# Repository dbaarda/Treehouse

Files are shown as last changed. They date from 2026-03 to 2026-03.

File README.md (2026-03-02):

# Treehouse README

## Introduction

I'm building a treehouse, and it needs to be documented.

## Contents

  Name          Description
  ------------- ------------------------------------------------
  README        This file.
  AUTHORS       The main project authors.
  THANKS        All the project contributors.
  COPYING       Copyright and licencing details.
  INSTALL       Installation instructions.
  USAGE         Usage instructions.
  SUPPORT       Support details and instructions.
  DEVELOPMENT   Development details and instructions.
  DESIGN        Design details and description.
  TODO          List of outstanding tasks and future plans.
  NEWS          Summary of fixes and changes for each release.
  ChangeLog     Detailed development change history.
  doc/          Contains project documentation.
  src/          Contains project source code.
  tests/        Contains project unit and functional tests.

in the distribution for bits and pieces.

## Credits

This should list original authors, significant contributors, and related
contributing projects.

See AUTHORS and THANKS for contributors to this project.

## Conditions

be the copyright and licencing terms and condtions.

See COPYING for the copyright and licencing details.

## Install

See INSTALL for installation instructions.

## Usage

reference to man pages or documentation in doc/, or the following;

See USAGE for usage instructions.

## Support

including mailing lists, discussion forums, online documentation,
trackers, etc. It should also include instructions or pointers to
instructions on procedures and conventions when using them.

### Documentation

documentation, FAQ\'s etc.

<http://www.project.net/>

:   The project homepage.

<http://wiki.project.net/>

:   The project wiki site

### Discussion

forums, giving any necissary subscription information etc.

<http://lists.project.net/project-announce>

:   Low volume project announcements list.

<http://lists.project.net/project-users>

:   User discussion list.

<http:///lists.project.net/project-devel>

:   Developer discussion list.

### Reporting Problems

any useful links.

<http://www.project.net/doc/bug_procedure.html>

:   Online instructions for reporting bugs.

<http://tracker.project.net/>

:   The projects bug tracker.

## Development

See DEVELOPMENT for development instructions.

## Design

See DESIGN for the design details and description.

## Plans

See TODO for future plans.

## History

See NEWS and ChangeLog for past history.

------------------------------------------------------------------------

<http://project/url/README> \$Id: README,v 82b72fe70897 2021/03/12
00:35:22 abo \$

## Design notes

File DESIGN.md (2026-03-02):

# *Project* DESIGN

::: contents
**Contents**
:::

## Introduction

### Identification

This is the \<Software Design Document\> for the \<Project Name\>.
\<Project Name\> is being developed according to \<SDP-DocId\>
\"Software Development Plan for the \<Project Name\>\". The requirements
for \<Project Name\> are identified in the \<SRS-DocId\> \"Software
Requirements Specification for the \<Project Name\>\".

### Document Overview

### System Overview

## Design Details

### Inspirations and Origins

### Design Philosophy

### General Architecture

#### Wall bracing

Diagonal bracing is needed for walls, floor and roof.

Turns out it's pretty much essential for ensuring your walls are true/square.
I used ratchet-straps to bring the walls square before putting on the
gavanized strapping to ensure the strapping was tight enough... there's a
limit to how much the strap tightners can do. Another tip; put the first nail
all the way through a strap-hole, tilt the nail a bit in the direction you
want to tighten it before starting to hammer it in. As it goes in it will pull
the strap tighter.

Need additional 4.5*2 + 1.8*2 = 12.6m

#### Cavity Battens

Using foilboard as the moisture barrier for both walls and roof means I'll
need cavity battens for both.

Cavity battens are to give a cavity gap between the wall
foil/moisture-barrier/sarking and the outer cladding. This gap is so moisture
that gets to, or condenses on, the barrier can drain down and to allow airflow
to help evaporation. The cavity also improves foil insulation performance with
gaps of at least 20mm recommended, but 10mm is sufficient for drainage/ventilation.

The bottom of the cavity is sealed with a perforated cavity closer that allows
drainage/airflow but blocks pests. Sometimes there is also a cavity top-vent
to give even better airflow while preventing easy water ingress.

For vertical corrigated sheet cladding an alternative cavity-closer is
flashing that protrudes past the outer edge of the cladding, leaving a small
gap for ventilation but small enought to prevent pests.

Simple cavity battens are normally rectangular profile strips installed mostly
vertically on top of the barrier and attached to the studs behind them. The
attachments are usually staggered nails, leaving the middle of the batten
clear to put the horizontal cladding attachments through (long nails or
screws), but sometimes glue or tape fixing is sufficient and the cladding
attachments through the batten to the studs becomes the primary attachment.
This vertical batten arrangement gives a clear gap for moisture to drain down.
They can also sometimes be put horizontally on top of noggings, but then there
is a minium 50mm gap on either end to allow vertical drainage/airflow and they
are mounted at a 5deg angle to drain water off them.

For mounting wall cladding vertically instead of horizontally, the attachment
points tend to be horizontally aligned, requiring the cavity battens to be
horizontal. For this castellated cavity battens are normally used. These
include castelated cutout "gaps" on both sides of the batten to allow vertical
flow/drainage past them on both the barrier side, and the cladding side. They
also include a 13|15|18 degree bevelled/sloped top side so that moisture drains
away from the barrier towards the cladding. Sometimes the bottom is also
bevelled to prevent moisture wicking back to the barrier on the bottom of the
batten. In theory a drip-cut could also help, but I've not seen that.
Standards require at least 1000mm^2/m worth of gaps past the batten, but most
castelated battens have at least 2x that much, with 20x5mm castelations
alternating on both sides.

With horizontal battens, there is often not a corresponding horizontal line of
noggings/studs to directly attach the batten to. In this case, structural
battens can be used, which are strong enough to directly attach the cladding
to without a stud directly behind the cladding attachemnt point.

There are also platic battens, that usually have corrigation-like ventilation
through them for mounting horizontally. They are typically not structural.

https://www.ventsystems.com.au/products/vb20-wall-cavity-batten/

For the walls, with vertical polycarbonate cladding we need horizontal cavity
battens. Note that the greca profile is itself already "castelated" with
16mm/2 * 1000mm = 8000mm^2/m of ventilation even if directly attached to the
foilboard. However, foil insulation will do better with an additional gap. We
can get away without castelated battens provided we either have regular 50mm
gaps and mount them on 5deg angles (a pain), or put a bevelled edge on the top
(and probably bottom) to drain towards the cladding to run down the greca
"castelation gaps". Given the castelation gaps, we can probably get away with a
smaller gap of maybe even 5mm?

For the roof, the structural roof battens that the polycabonate roofing is
attached to are run "horizontaly" perpendicular to the roof slope. This means
we cannot just put them on top of the roof foilboard membrane, but need to add
"vertical" cavity battens under them over the rafters. The roof battens add a
35mm gap between the foilboard and roof sheeting which helps insulation, and
the sheet "castelation gaps" allow "vertical" airflow over the roof batten,
but a gap is still needed for drainage flow under them. These are sometimes
called "counter-battens".

The roof cavity battens need to provide a drainage gap of at least 5mm under
the roof battens. They also need to help distribute the load from the roof battens
so that it doesn't just crush into the foilboard. This means we can't just put
square spacers under where the roof-battens attach through the foilboard to
the rafters.

We are going to need 3 walls * 4 strips * 3m + 1 wall * 3 strips * 3m + 8 rafters
* 3.6m ~= 75m of cavity battens.

I originally thought of using [Weathertex 1220 x 45 x 9.5mm Cavity
Batten](https://www.bunnings.com.au/weathertex-1220-x-45-x-9-5mm-cavity-batten_p0240107)
which work out as $2.15/m. 

Then I realized I could cut a 90x35mm MPG10 beam into 8 35x9mm cavity battens.
For a more normal batten size that would distribute the foilboard load a
little better you could cut 6 44x10mm battens, or use 90x45 for 8 45x9mm
battens. For MPG10 H3 90x35mm costing $5.95/m the battens would be ~$0.75/m or
~$1/m, and for MPG10 H3 90x45mm costing $7/m they would be $0.88/m.

Wooden battens must be at least H3 treated to protect them from rot, and cut
H3 timber needs to be re-treated on the cuts with H3 level timber
preservative. Cut into strips like this so much needs re-treating you might as
well use untreated pine (MPG10 untreated 90x35 for $4/m, or $0.50/m battens)
and treat it all afterwards, or even non-structural pine (non-structural 90x45
$3.20/m or $0.40/m).

Bunnings only has sprayon cut sealers, 300g for $19.50. There is also
brushon/soak stuff available at Pestrol Australia at 2L for $49.90. You need
0.25l per m^2, or about 70m of 45x10mm battens per 2L tin, adding $0.71/m to
the cost, bringing even the cheapest non-structural battens to $1.11/m.

* [TWA Woodcare 300g Ecoseal Tanalised Timber Treatment
(H5)](https://www.bunnings.com.au/twa-woodcare-300g-ecoseal-tanalised-timber-treatment_p0960107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)

* [Tanalised 300g Clear Enseal Timber Treatment
(H3)](https://www.bunnings.com.au/tanalised-300g-clear-enseal-timber-treatment_p0960108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)

* [XJ Timber Preservative 2L](https://www.pestrol.com.au/buy-online/xj-timber-preservative/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)

This makes the Weathertex battons look more appealing. Less work and no nasty
treatment costs/process. They will probably still need bevelling for the
horizontal wall battons. Not much info on what they are made of (hardwood?)
but I suspect it's a hardwood composite that will not need treating.

Other options are [permatimber 42 x 18mm DAR]
(https://www.bunnings.com.au/permatimber-42-x-18mm-2-7m-arctic-white-pvc-composite-dar_p0497592)
cut into 2 42x7.8mm battens ($5.44/2 = $2.72/m battens).

[42x11mm 5.4m H3 Treated Pine FJ DAR Primed
LOSP](https://www.bunnings.com.au/42-x-11mm-5-4m-h3-treated-pine-fj-dar-primed-losp_p0020736)
used as-is for 42x11mm battons ($4.11/m), but will also need beveling and cut
treating.

[QuickBoard 300 x 9mm 2.7m Arctic White PVC VJ Wall and Ceiling Lining Board -
2
Pack](https://www.bunnings.com.au/quickboard-300-x-9mm-2-7m-arctic-white-pvc-vj-wall-and-ceiling-lining-board-2-pack_p0497624)
cut into either crosswise 60 45x9x300 bits that can be chained together ($59/2/(2700/45)/0.3 = $1.64/m), or 6
45x9x2.7m strips ($59/2/6/2.7 = $1.82/m). Note these are hollow, hence chained bits would be like a
vented plastic batton.

[QuickBoard 300 x 9mm 2.7m Antique White PVC VJ-Crown
Reversible](https://www.bunnings.com.au/quickboard-300-x-9mm-2-7m-antique-white-pvc-vj-crown-reversible-2-pack_p0497612)
cut into 6 45x9x2.7m strips ($89/2/6/2.7 = $2.74/m).

[Brutus 6 x 38mm x 3m Building Moulding Cover
Trim](https://www.bunnings.com.au/brutus-6-x-38mm-x-3m-building-moulding-cover-trim_p1100628)
$10.92/3=$3.64/m

XPS foam! This is a DIY version of [Ametalin 2750x43x12mm ThermalBreak
strips](https://www.bunnings.com.au/ametalin-2750mm-x-43mm-x-12mm-thermalbreak-strips-r0-25-pack-of-50_p0401288)
which cost $458.07/(50x2.75) = $3.33/m. Compression strength is about 200kPa,
so a 70x50mm patch can take about 71kg or a 50mm strip can take more than 1000Kg/m.  Note foilboard compression
strength is about 70kPa so about 250kg/m on a 35mm wide joist. A 1200x600x50mm
sheet cut into 50 1200x50x9.5mm battens (table saw 2.5mm swarf) or 60
1200x50x10 battens (hotwire) ($29.8/(50x1.2) = $0.50/m).

https://www.bunnings.com.au/bastion-1200-x-600-x-50mm-xps-multi-use-foam-board_p0461084

Fluteboard! It looks very similar to vented cavity battens. Note it can also
be used as a cavity closer! The following cavity battens and all the related
products look like they have been made from laminated fluteboard;

https://www.ventsystems.com.au/products/vb20-wall-cavity-batten/
https://proctorgroup.com.au/construction-membranes/proctorpassive-drainage-batten-db-fr/

It's hard to get data on compression strength, but it looks like it will be
between 140kPa and 1.4MPa(???) Testing a 4x5cm piece of corflute it took about
30Kg before it collapsed. Thats 30*9.81/(0.05*0.04)=147150Pa=147kPa which
matches the 140kPa number above. A 70x50 patch can take only about 50Kg, or
for a 50mm strip about 713Kg/m. As per the cavity battens, it seems 4mm holes
are a sweet spot to prevent capilary action and block pests, so the
1200x900x5mm $14 tunnelcore is the thinest you'd want. There is also
2250x1220x8mm $35, which gives a bigger gap, but the holes a bigger and might
need a mesh. Note metal mesh with <2mm holes is a requirement for fire safety
to protect against embers, so maybe we need a mesh anyway.

You might want to stack 2x5mm for 10mm or 4x5mm for 20mm, if you do you could
"brick" the layers to get wider than 900mm lengths. Unfortunately
polypropyline is a bitch to glue;

https://forgeway.com/learning/blog/bonding-polypropylene-with-glue

There are special polypropyline glues but they are complicated and very
expensive. Corflute suggests hot glue or double sided tape. Other sites
suggest contact-adhesive. I've seen suggestions to use welding with a hot-air
gun, which would work well but might be very hard to do properly without
deforming everything. There is also triple-wall fluteboard available
(2200x1100x10mm $55.30, min purchase 5 for $276.49), but it's harder to find;

https://www.silverback.com.au/FLUTEB/Flute-Board-Gorilla-Sheets/pd.php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

Note that ultimately these will be mechanically fixed together with the
wall/roof mounting screws that go through to the frame/batton, so the strength
of the laminating bond probably doesn't matter much. Perhaps a light
heat-weld, contact adhesive, or double-sided-tape would be enough?

Testing with cheap double-sided tape, expensive double-sided tape, and cheap
contact adhesive, they all worked really well, way better than is required. I
suspect this is because the white tunnelcore is "corona treated" to make the
surface easier to print on.

Cutting a 1200x900x5mm sheet and laminating two layers can give 13 900x45x10mm
battens ($14/13/0.9 = $1.20/m), or can be "bricklayed" into longer battens.

2440x1220x5mm sheets can be bought on ebay, but only in packs of 10 for $340.

Using a single layer 2250x1220x8mm cut into 50 1220x45x8mm battons $35/50/1.22
= $0.57/m

This could also be done using [Sunlite 8 1200x610x8mm Clear Twinwall
Polycarbonate Sheet](https://www.bunnings.com.au/sunlite-8-1-2-x-0-61m-clear-twinwall-polycarbonate-sheet-1200mm_p1010852)
giving 25 0.61mx45x8mm battens ($29.76/25/0.61 = $1.95/m), or [Sunlite 10mm
Twinwall 1000x980x10mm Clear Polycarbonate Roofing $36.80
](https://www.bunnings.com.au/sunlite-10mm-twinwall-x-1-0m-clear-polycarbonate-roofing-1000mm_p1010830)
giving 21 0.91mx45x10mm battens ($36.80/21/0.91 = $1.93/m).

Finally, what about cutting strips of foilboard to use as a cavity batten?
cheap, and dispite the good enough compression strength, too easy to snap to
be worth even trying? The 10mm foilboard is a tiny bit cheaper than 8mm
tunnelcore per m^2.

#### Ventilation and Drainage

The http://ventsystems.com.au/ provides both an awesome set of ventilation
products, and a wealth of information on design and standards. Sadly their
products don't seem easy to get, and are probably really expensive. Their docs
pointed me at the existing standards, which are also freely available and very
good;

https://ncc.abcb.gov.au/editions/ncc-2022/adopted/housing-provisions

Standards say for a <10deg traditional mono-pitched roof requires 25000mm^2/m
at opposing ends of the roof. That's effectively a 25mm ventilation gap on the
entire length of the top and bottom sides of the roof.

For walls, NZ regs require cavity closers to have at least 1000mm^2/m at the
bottom. Top vents appear to be recommended but optional. I cannot find
Australian regs except related to fire protection which required metal mesh
with max 2mm openings to block embers from getting into the cavity. It seems
NZ regs are the leaders on wall cavity best practice.

The wall cavity gaps between foil/sarking is recommended to be 20mm, but with
profiled sheets the crests add their own 16mm cavity (avg 8mm gap). Also, the
20mm gap was largely to avoid "bulging of underlay" closing the gap, which
cannot happen with foilboard, and studies say a 10mm gap is probably
sufficient. Castelated cavity battens have 5mm deep gaps, and So I belive 9~10mm cavity battens would be sufficient for the
walls.

#### Tree holes

Holes for branches through treehouse walls, floors, and roofs need to be
somehow sealed against insects/rain/etc while still allowing the trees to grow
and move in the wind.

Holes at the floor level will have 40mm of clearance around the tree to allow
for alignment errors, tree growth, and movement.

Higher up in the tree branches are thinner and can move more, so we allow 50mm
of clearance.

Sealing the hole needs a flexible but robust seal against the tree to the roof
sheets, wall cladding, or floor. This needs to have a water-tight seal to the
external boards/sheets/cladding that will not interfere with the water flow.
It should also be robust enough to resist critters and have strong UV/weather
resistance.

Also, another layer of sealing should be done for the foilboard moisture
barrier, which should also be watertight. This should be protected by the
outer layers from critters/UV/weather, so it does not need to be as robust. It
needs to have a waterproof attachment to the foilboard.

The attachment to the tree needs to be waterproof without hurting the tree or
restricting growth and movement. This means it needs to have minimal (ideally
zero) holes/screws/etc into the tree, and be loose or stretchy enough to not
hurt tree growth and cause tree girdling injurys.

These suggest a flexible rubber membrane attached to the tree and treehouse
with butyle tape. To go around the tree it needs to be initially wrapped and
then joined to itself with a waterproof seam. Joins and seams can be
reenforced with pop-rivets through punched holes and small washers, and sealed
with butyle tape.

The butyle tape needs to be stretchy, without any fiber/fabric/aluminium
re-enforcement that limits the stretch. double-sided pure butyle looks to be
the best option.

For the outside, rubber tubes seem best. These are a UV and weather resistent
butyle rubber (I think) that is about 2mm thick. It should stick well with
butyle to both the tree and treehouse. The hard part is finding tubes big
enough? bunnings has wheelbarrow tubes up to 390mm outside, 200mm inside
diameter. Larger tubes seem hard to find.

Attaching the tubes to the roof/wall sheets can be done with rivets, but care
must be taken when riveting polycarbonate. The polycarbonate hole needs to be
1.5x the rivet diameter to avoid radial stresses and for thermal expansion,
and a backup washer with laminated rubber is recommended;

https://www.theplasticshop.co.uk/plastic_technical_data_sheets/lexan_polycarbonate_sheet_processing_guide.pdf

Another possiblity is plastic rivets. It might even be possible to 3D print my
own rivets, but [weather resistant
filaments](https://www.matterhackers.com/articles/the-best-3d-printing-filament-for-outdoor-use)
like
[ASA](https://www.inkstation.com.au/2102/asa-3d-filament-175mm-black-1kg-roll-p-24990.html#25329)
can be hard to work with. Would need a [high-temp
nozzle](https://www.ebay.com.au/itm/315402989256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).
I have now bought some ASA and a nozzle so I can print any required outdoor
parts.

For the inner seal, I was thinking silicone would be best; it's very weather
resistant and robust. However, it's hard to find in sheets thin enough, and
bonding to it is really really hard. I've tested butyle against my silicone
work mat and it really doesn't stick. Making it stick to itself and seal after
going around the tree will be really hard. I did find special primers that can
be used with super-glue for making silicone rubber stick, but it's literally
hundreds of dollars for a tiny bottle. Other types of rubber sheet are even
harder to find.

The ideal thickness/stretchyness is physio resistance bands. The come in a
variety of color-coded thicknesses 15cm wide rolls and are pretty cheap. They
are latex rubber, which doesn't have a good reputation against weather, but
being the under-layer moisture-barrier, maybe that doesn't matter. And
boy-oh-boy, does butyle stick to them! The rubber will literally rip before
coming free. rivet re-enforcemnts will not be required.

The tree hole sizes are (clockwise from trunk near origin) circumfrance is as
measured;

Note circ-i is tree circumfrance and circ-o is hole plus 30mm overlap outside
circumfrance.

hole   tree    gap Dmm  D"    circ-i  circ-o tubes
Floor1 360x340 40  ~340 13.4"   1030  1470   12"  1.5x
Floor2 240x230 40  ~240  9.4"    750  1190    8"  1x
Floor3 380x300 40  ~340 13.4"   1030  1470   12"  1.5x

WallR  247x166 50  ~210  8.3"    650  1150    8"  1x (half)
WallF  630x290 50  ~460 18.1"   1440  1940   16"  2x
			       	              
Roof2  295x208 50  ~240  9.4"    750  1250    8" 1x
Roof3a 275x225 50  ~250  9.8"    790  1290    8" 1x 
Roof3b 250x143 50  ~210  8.3"    650  1150    8" 1x
Roof4  280x280 50  ~280 11.0"    880  1380   10" 1x (half)

10 required, 2 per tube, = 5 tubes of bunnings Move It 650 x 8 $12.95 requred.
Alternatively, it might be good to get one big 16" for the wallF hole.

The inner diameter of these is 20cm (63cm circumfrance) and outer is about
38cm (120cm circumfrance) but can stretch the inner to 28cm (90cm
circumfrance), with a strip width of 13.2cm giving you two per tube. Note
inner+width!=outer diameter, because it's conical when flat.

kmart bike tubes are cheaper $6 each and in sizes 40/50/66/70/74 cm inside
diameter, but are only about 3cm wide? The $10 66x4.8cm one is a tiny bit
wider, but not enough. Even motorbike tubes are not wide enough. Unfortunately
car tubes seem to be hard to find (there are some on ebay) and more expensive.

The total (inner) circumfrence length is 8.1m, and the outer length (not
including attachment border) is 10.7m. Adding attachment border is about
13~14m So we need about 15m of 15cm wide latex strip, and about 6 bunnings
tubes.

#### Windows

Docs online have lots of different recommendations.

Lots of docs say it's important to have sloped sills AND backdams. Some say
sloped sills OR backdams. Some say to use manufactured kit or sheet metal sill
pan flashing. Others say to use wall wrap and self adhesive membrane or tape
flashing over the rough opening.

The rough opening can be sloped using either a sloped sill-wedge on top of the
rough opening sill plate, sloping the sill plate by cutting an angle on the
cripple stud ends, or ripping an angle to the top of the sill plate. A backdam
can be added with strip of wood or self-adhesive gasket.

The sill-wedge slope should be at least 1:15 (3.8deg) with 5deg (7:80 or
~1:11) being commonly used. The recommended minimum slope for drainage of
window sills is 1/4 (14deg or roughly 15deg), but also 1/8 (7deg) is common.

Older designs have a full windowsill on top of the sill plate with a 1/4 slope
(14deg) and drip-cut on the bottom. But this doesn't seem to work well with
modern aluminium windows. These are typically used when building the window
in-place and the sill forms the bottom of the window frame, but I've seen some
wooden units with bottoms sloped to sit on a sloped sill (or sloped sill
plate?).

Most window installation docs just have a flat rough opening with flashing, no
slope or backdam. Most standard windows have a flat base, so installing them
in a sloped opening requires sloped packing shims. Note that shims are not
supposed to go the full width of the sill-plate, and the gap between shims and
the sill-plate and reveals is important for drainage;

https://www.appliedbuildingtech.com/system/files/nrc-irc_window_sill_details_for_effective_drainage_of_water.pdf

https://cdnassets.hw.net/dd/3c/e598bb1e45c9af6481862c7a85ed/2010-04-bateman.pdf

https://www.marvin.com/blog/10-most-common-window-installation-mistakes

Aluminium windows often have a narrow frame with nailing fins to mount them
from outside flush against the wrapped rough openening which can then be
sealed against the wall membrane with flashing tape. Or sometimes the fins are
attached to the reveals which are then screwed to the rough opening, with
flashing and/or flashing tape used to seal the gap between the fins and the
outside edge of the rough opening, similar to how prefabricated timber framed
windows are installed. This doesn't work well with a full sill in place, and
the windows have their own integrated minimalistic sill and window trim
designed to sit over the cladding. Sometimes a false sill is installed under
the window for the look and/or to drain the water away from the cladding.
Reveals are used to line and seal the inside of the window cavity against the
aluminium frame, with different reveal widths for different wall thicknesses.

Wooden window units tend to have the internal reveal integrated and no
mounting fins. Instead they are inserted from the inside and screwed to the
rough opening sides through the integrated reveals with them flush to the
inside wall lining. The integrated reveal+frame should be wide enough so the
outside edge of the frame aligns or slightly protudes past the external
cladding.

https://www.bunnings.com.au/diy-advice/home-improvement/doors-windows/how-to-install-a-timber-awning-window
https://www.stockwindows.com.au/product/timber-awning-window-600h-x-1210w-2/

Undersides of sills, sashes, and heads should have drip groves cut, about 2~3mm
wide, 2~4mm deep, and about 7mm back from the edge.

##### Double glazing

Glass can be 4mm to 10mm thick, with higher thicknesses helping insulation of
both heat and sound. There are also special insulating/tinted/etc glasses.

Gaps can be filled with (in increasing cost/quality) air, argon, krypton or
vacuum. Gaps can be 6 to 20mm, with the ideal gap depending on the gas and
heat vs sound insulation objectives. Bigger gaps insulate sound better, but
there is an ideal gap per gas for insulation (to small gives conduction, too
big gives convection). It seems 12mm is the sweet spot for air/argon, but many
argue 14mm or 16mm is better.

4mm glass/10mm gap/4mm glass seems common.

Aim for 12mm gap.

Also need desicant to absorb moisture. 

### Braiding

I used braided macrame cord to make straps to wrap around the trees above
their entry into the treehouse as "chain drains" to divert water running down
the trunks away before it gets to the entry hole.

It's useful to know how much longer the cord needs to be. A 4-strand flat
braid uses 1.5x, a 4-strand circular braidabout 1.3x the cord length. Macrame
with 4 strands uses 4x the length for the outer strands, so by switching the
inner and outer strands periodically it averages 2.5x the chord length. Using
a mixture of braiding and macrame it's possible to create varying densities.

## Indexes

### Definitions

TLA

:   Three letter acronyms.

aterm

:   a definition of the term.

### References

-   <http://related.com/url>

------------------------------------------------------------------------

<http://project/url/DESIGN> \$Id: DESIGN,v 221032f84299 2021/03/12
00:34:53 abo \$

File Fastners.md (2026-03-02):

##Sizes

Note sizes typically measure the OD of the fastner, but the ID of washers is
larger. For metric washers they are larger by the smaller of 5-10% in 0.1mm
increments or 1mm.

https://www.boltandnut.com.au/media/dz_product_pdf/Metric%20to%20Imperial%20Chart.pdf

$ ./met2imp.py
M1.6  1.6mm 0.063"    1/16"         
M2    2.0mm 0.079"    5/64"         
M2.5  2.5mm 0.098"    3/32"         
M3    3.0mm 0.118"     1/8"     1/8"
M3.5  3.5mm 0.138"    9/64"         
M4    4.0mm 0.157"    5/32"         
M5    5.0mm 0.197"   13/64"    3/16"
M6    6.0mm 0.236"   15/64"     1/4"
M8    8.0mm 0.315"    5/16"    5/16"
M10  10.0mm 0.394"   25/64"     3/8"
M12  12.0mm 0.472"   15/32"     1/2"
M14  14.0mm 0.551"   35/64"    9/16"
M16  16.0mm 0.630"     5/8"     5/8"
M18  18.0mm 0.709"   45/64"         
M20  20.0mm 0.787"   25/32"     3/4"
M22  22.0mm 0.866"   55/64"     7/8"
M24  24.0mm 0.945"   15/16"       1"
M27  27.0mm 1.063"  1-1/16"         
M30  30.0mm 1.181"  1-3/16"   1-1/4"

1/8"     0.125"  3.2mm M3  
3/16"    0.188"  4.8mm M5  
1/4"     0.250"  6.3mm M6  
5/16"    0.312"  7.9mm M8  
3/8"     0.375"  9.5mm M10 
7/16"    0.438" 11.1mm     
1/2"     0.500" 12.7mm M12 
9/16"    0.562" 14.3mm M14 
5/8"     0.625" 15.9mm M16 
3/4"     0.750" 19.0mm M20 
7/8"     0.875" 22.2mm M22 
1"       1.000" 25.4mm M24 
1-1/4"   1.250" 31.8mm M30 

##Rivets

Standard sizes;

diameter: 2.4(3/32") 3.2(1/8")* 4.0(5/32") 4.8(3/16")* mm
grip: 3.2* 4.8* 6.4* 7.9 9.5* 12.7 15.9 mm
variants: countersunk wide-flange sealed 
material: aluminium* steel stainless

* most common variants

##Washers

materials;

stainless
brass
zinc-steel
galv-steel

##3D Printing

Common materials;

Material Cost-$/kg g/cc E   Ts  Fs  Dur Prt Ptemp Btemp Properties
-------- --------- ---- ---- --- --- --- --- ----- ----- ----------
PLA+       $26.90  1.23 1.97 60  90   4   9  215   50   Easy printing
PETG       $29.90  1.27 1.07 52  58   8   9  240   80   Strong, Easy printing
ABS        $24.90  1.04 1.18 43  66   8   8  240  100   Strong, Acetone smoothing
Nylon      $43.90  1.12 1.37 52  58  10   8  265   80   Wear resistant (gears)
TPU        $42.90  1.12      52       9   6  240   50   Flexible
PVA        $89.80  1.23                                 Water sol (supports)
PVB        $59.95                                       IPA smoothing
ASA        $38.90  1.00 4.30 50  35  10   7  240  100   Weather resistant, Acetone smoothing
HIPS       $24.90  1.03                                 Limonene sol (supports)
POM        $49.90  1.4g                                 Wear resistant (gears)

Note ASA is $0.039/cc, PLA+ is $0.033/cc. Factoring in waste it's about 4c/cc.

Fastners like these;

https://www.amazon.com.au/FOUNDCOOL-Popular-Universal-Retainers-Fasteners/dp/B09WYYXBTT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

Are about 1-2cc's or 4~8c of plastic, and can be bought for about 10-20c each
in bulk. Given the better quality of the manufactured parts they are probably
not worth printing unless you have need for very specific geometries.

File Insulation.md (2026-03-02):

#Insulation

Insulation is all about heat energy capture/transfer via mechanisms;

* conduction - transfer of heat through materials via contact.
* convection - transfer of heat through airflow.
* radiation - transfer of heat across "transparent" gaps as emitted/absorbed
radiation.
* storage - heat energy stored in materials exposed to a high temperature that will be
released when exposed to a lower temperature.

##Conduction

Note K is degrees kelvin, which has the same scale as degrees Celcius, but a
different zero offset. So K and C can be used interchangably here. I just use
the word "degrees".

K-value (also lambda) - thermal conductivity of a meterial in W/m.K. This is
how many Watts of heat energy pass through per m^2 of surface, per heat
gradient in degrees per meter of depth. (W/m^2) / (K/m) = W/m.K. A steeper
heat-gradient (bigger temp difference and/or thinner layer) means more energy
gets through. High values mean more heat conducted through.

U-value (sometimes also called C-value. Sometimes C-value is for insulation
material, but U-value is for a whole system) - thermal conductivity of an assembly
or insulation layer in W/m^2.K. This is how many watts of heat energy pass
through per m^2 of surface per degree of temperature difference between inside
and outside. For a sheet of insulation, U is the K value divided by the
thickness in meters; (W/m.K) / m = W/m^2.K. For complicated assemblies with
multiple layers/frames/etc the U value is typically the combined/average over
the whole window+frame area. High values = more heat through.

R-value - thermal resistance in m^2.K/W. The square meters of surface area per
watt of thermal heat that gets through per degree temperature difference.
(m^2) / (W/K) = m^2.K/W. Alternatively, the temperature difference maintained
per watt passing through each square meter; (K) / (W/m^2) = m^2.K/W. R values
for insulation are typically calculated by dividing the thickness by the K
value. High values = less heat through. Note the R values of each layer can be
added together for the total R value.

L-value - sometimes used for the insulation thickness in m.

U = 1 / R = K / L

Example K-values.

Mineral wool: 0.03 - 0.04 W/mK
polypropylene 0.22 W/m·K 
polycarbonate 0.22 W/m.K
Expanded polystyrene: 0.03 - 0.04 W/mK
Extruded polystyrene: 0.02 - 0.03 W/mK
Polyurethane foam: 0.02 - 0.03 W/mK
Foilboard: 0.0366 W/mK
Cellulose fibre: 0.04 - 0.05 W/mK
Hardwood: 0.10-0.21
SoftWood: 0.08-0.17 W/mK
pine: 0.12 W/mK
MDF: 0.05-0.14  W/mK (for 250-800kg/m^3, most MDF sheets are 800kg/m^2)
Air at 0C: 0.024 W/mK
Red Brick: 0.6 W/mK
Glass: 0.8 W/mK
Steel: 50.2 W/mK
Iron: 79.5
Aluminium: 205.0
Concrete: 0.8
Water at 20C: 0.6

https://www.engineeringtoolbox.com/conductive-heat-transfer-d_428.html

Heat transferred due to conduction is;

q = U * A * dT

## Convection

https://www.engineeringtoolbox.com/convective-heat-transfer-d_430.html

heat transfer due to convection is;

q = hc * A * dT

Note this is the same as heat conduction where hc is the U value for
convection. The aprox hc value as a function of air velocity is;

hc = 12.12 - 1.16*v + 11.6*sqrt(v) # From ??? replaced with below
hc = 10.45 - v + 10*sqrt(v) # from https://www.engineeringtoolbox.com/convective-heat-transfer-d_430.html 

Note for still air v=0.0m/s this gives U=10.45W/m^2.K or R=1/10.45=0.0957,
which is about the same as conduction through 2->2.5mm of air without
convection. This is less insulation than quoted for indoor air R=0.12 which
was presumably for still air, but it is more insulation than outdoor air
R=0.04 which would include wind. However, the above formula is described as
"an empirical equation and can be used for velocities 2 to 20 m/s".  Any
induced convection currents would be way less than 2m/s so the above formula
is probably not useful.

Airgap R values,and possibly those indoor/outdoor air R values, are for a
mixture of radiation, conduction, and convection. The conductivity of air
depends on temperature and pressure, but at atmospheric pressure it's between
0.024-0.027W/m.K for 0-40C, or around 0.026W/m.K at 25C. 

https://www.engineeringtoolbox.com/air-properties-viscosity-conductivity-heat-capacity-d_1509.html

Thermal convection in airgaps means that gaps larger than 30mm provide no
additional insulation. Increased conduction distance is overcome by the
induced convection. Note that 30mm is also the practical limit for unfoiled
gaps with e=0.9 because heat transmission from radiation starts to dominate.
For radiation the distance doesn't matter, so even an infinite e=0.9 gap or
vacuume is U=5.43 or R=0.184.

Induced convection currents definitely do make a difference giving different
horiz/up/down R values. The following quoted R0.22 for "unventilated
non-reflective airspace" in a roof exceeds R0.18 for radiation@25C e=0.9,
which suggest convection might even transfer some heat back up, effectively
exceeding the performance of a vacuume in resisting heat flow down? Or are R
numbers just generally very fuzzy?

https://www.abcb.gov.au/sites/default/files/resources/2022/UTNCC-Thermal-bridging-case-study-example-03.pdf

For vertical surfaces I wonder if you can think of it in terms of a "boundary
layer" of still air with the temperature gradient and pure conduction across
it. The more "wind" the thinner the "boundary layer". An air-gap has two
boundary layers for the inner and outer layer, giving better than
outside/inside R values?

## Radiation

The amount that a surface absorbs and emits radiant heat is its "emittance".
Foil is low-emittance (e=0.05), anti-glare foil is medium emittance of e=0.4.
For white plastic e=0.84. All other surfaces considered to have e=0.9. A
"black body" would be e=1.0, absorbing and radiating 100% radiant heat. Note
that a surface's ability to absorb heat matches its ability to radiate it,
which is why the best heatsinks are black, and also explains why foil works
equally well on either side of a cavity. More detailed emissivity constants
are at;

https://www.engineeringtoolbox.com/emissivity-coefficients-d_447.html
https://www.thermoworks.com/emissivity-table/

The formula for heat radiated from a hot body to a colder space is

  q = e*Sigma*(Th^4 - Tc^44)*Ah                                    

where

  q = heat radiated in W.
  e = surface emissivity 0.0-1.0
  Sigma = = 5.6703e-8 (W/m^2.K^4) - TheStefan-Boltzmann Constant
  Th = hot body absolute temperature (K)
  Tc = cold surroundings absolute temperature (K)
  Ah = area of the hot object  (m2)

https://www.engineeringtoolbox.com/radiation-heat-transfer-d_431.html

Notice this is T^4, so it's not a simple linear eqn with dT. However, for the
small 0degC->50degC range it doesn't vary too much so can kind of be
considered constant, but I think some foil systems use different typical
winter vs typical summer temperatures to give different in/out R values for
even vertical foil+airgap configurations.

The U value is higher for higher temperatures, which might explain why
Foilboard has a different in/out or summer/winter R values for vertical-cavity
walls. In summer temps in the void would be higher, giving the void higher
radiation U values. So the void is less effective insulation during summer.

U for different e at different temps are;

e    10C   20C   25C   30C   40C
---- ----- ----- ----- ----- -----
1.00 5.17  5.73  6.03  6.34  6.99
0.90 4.65  5.16  5.43  5.71  6.29
0.85 4.39  4.87  5.13  5.39  5.94
0.10 0.517 0.573 0.603 0.634 0.699
0.05 0.258 0.287 0.302 0.317 0.349

Note that this would be for a pure vacuume. In practice there is also
conductivity and convection happening, so the R values will be lower than
that. You can add the radiation U value to the conduction/convection U value
to get the overall U value.

### Foils

Note foil insulation works by reflecting radiant heat, not resisting
conduction. So technically, foil doesn't have any R value. Any R ratings for
foil insulation are normally calculated by measuring the "total system R
value" of it's performance in a wall with cavity etc.

https://www.smartrate.com.au/media/articles/demystifying-air-gaps

https://www.continuousinsulation.org/sites/default/files/designpptairspacervalue.pdf

### Air gaps

Still air conduction/convection resistance increases as the gap increases up
to about 30mm, after which it remains nearly constant, so wider gaps don't
help. With increased venting convection becomes the dominant factor. Because
of buancy effects air gaps are given different Rhz/Rup/Rdn values. Sometimes
you also see different Rin/Rout values which account for different
summer/winter temperature radiance U values. The R value of an air gap depends
on emittance of the surfaces on either side. Low emittance surfaces (foil)
give high R-values.

https://help.iesve.com/ve2021/table_15_thermal_resistances_of_air_gaps.htm

An air gap with no foil is about R0.16. With foil is about R0.6? Note the
Foilboard calculation earlier has R0.71 for airgaps with foil. It seems it
doesn't matter what side of the gap the foil is on; foil both reflects
radiation back across the gap, and resists emitting radiation into the gap?
Would foil on both sides be even better?

So insulation can also perform differently resisting heat transfer
up/down/sideways due to convection in cavities, through material, etc,
resulting in higher resistance to heat going down compared to up. This is why
you get different "heat-flow-in" vs "heat-flow-out" R values, and you get
higher R values for roofs "in" and floors "out".

## Heat Sources

### Solar Radiation

Solar Heat Gain Coefficient (SHGC) - percentage of solar radiation hitting a
window/skylight/roof-sheet that ends up inside as thermal energy (heat)
inside. This includes transmitted radiation and absorbed and transferred in as
heat. 100% means all solar radiation turns into inside heat, 0% means none
does. For windows includes not just the glass, but the whole window frame.

single-glazed uncoated = 0.71
single glazed, grey = 0.53
double glazed, uncoated clear/clear = 0.61
double glazed, clear low-e (0.2) on surface 3 = 0.57
double glazed, clear low-e (0.1) on surface 2/ clear = 0.45

Shading Coefficient (SC) - older measure, does not consider frame, only glass
portion. ratio of heat compared to 1/8" single-glazed glass. Does take into
account exterior shading.

Note a "Peak sun hour" has 1000W/m^2 of solar radiation used for standard
solar panel rating. Solar panels are about 20% efficient so give about
200W/m^2 during a peak sun hour.

The "solar constant" has it at 1370W/m^2, though other sources have it as
1360W/m^2. One says 1380W/m^2 above the atmosphere, but about 1000W/m^2 "at
our latitude at the surface".

### Human Heat emmissions

Humans also release heat, which varies depending on activity;

https://help.iesve.com/ve2021/table_10_sensible_and_latent_gains_from_people.htm

Measured as both Sensible heat (80->190W), which is heat that directly raises
the temperature, and Latent heat (25->275W) which doesn't raise the
temperature, but raises the humidity (sweat), storing the heat energy in water
vapor which will be emitted when the vapor condenses.

Note that the combined Sensible+Latent heat energy generated by a 2m^2 surface
area human is max 465W or 232.5W/m^2, compared to 1000W/m^2 for solar radiation!

An idle human is just over 100W.

### Electric Heaters

Typical electric heaters emit about 1000W, but thermostats can down-regulate
this to the amount needed to maintain the desired temperature.

### Heat Pumps

Air conditioners can pump heat in or out, transfering more heat than they
consume, with a Coefficient of Performance (COP, heat output/power input) of
around 3->5 dependent on inside/outside temperature difference.

https://en.wikipedia.org/wiki/Coefficient_of_performance

Aircon units typically quote their cooling/heating capacity in W they can
removed/add, and their power usage. For a typical COP=4 heating efficiency
will be about 1/4 the heating capacity. It seems cooling is often a bit more
efficient with around COP=5, so they eat cooling capacity/4 power. Typical
sizes are 2.6kW-8.8kW of cooling;

https://www.kogan.com/au/buy/hyundai-88kw-inverter-smart-split-system-air-conditioner-reverse-cycle-hyundai/

### Suntuf

https://polycarbonate.com.au/domestic-product/suntuf/

For all U=5.8W/m^2.K which means they add R=1/5.8=0.17 insulation against
conducted heat. Note at only 0.8mm thick that suggests polycarbonate has
K=U*L=5.8*0.0008=0.00464W/m.K which is super insulating! However, other
sources quote polycarbonate as K=0.23W/m.K so it should be
U=K/L=0.23/0.0008=287.5W/m^2.K and R=1/U=1/287.5=0.0035. This suggests the
quoted U value must be including the corrigation air-gap effects... note an
air gap with no foil is about R0.16, so that probably explains it.

For SHGC I don't understand how heat transmission% can be higher than SHGC for
some suntuf colours. Is this what % of light shines through in the non-visible
spectrum, and light transmission is in the visible spectrum?

For Smooth Cream SHGC=0.331 and Sand Dune SHGC=0.305. This means 30~33% of
that 1kW/m^2 of peak sun will enter the roof cavity. The foilboard will
reflect 95% of that back, but I'm guessing that the polycarbonate will work
the same way in the other direction, so 70~67% of the reflected light will be
reflected back in, and out again etc. If you iterate this you end up with
<5% of the radiant heat getting in (4.54% cream, 4.49% sanddune), or about
45W/m^2.

The good news is the roof will be shaded by the tree, so it's likely to be
less than half that, or maybe 20W/m^2, or 180W total for 9m^2 of roof.

At 20W/m^2 heat going into the cavity, if it was sealed, you would then have
heat conducting out the polycarbonate to outside, and heat conducting in
through the foilboard to the house. Is simply treating it as 20W/m^2 heat
passing through the total R of the roof a good enough approximation? Probably
not.

### Foilboard

https://insulationessentials.com.au/wp-content/uploads/2022/10/Foilboard-Tech-Data-Sheet-JAN-22.pdf

Foilboard 15mm is quoted as 0.41 for just the board in this;

https://www.betaboard.com.au/content/userfiles/files/products/FOILBOARD/FOILBOARD%20THERMAL%20PERFORMANCE%20R%20Calc%20BV%2070mm%20Frame.pdf

Which suggests K= L/R = 0.015/0.41 = 0.0366.

10mm foilboard in theory has R = L/K = 0.01/0.0366 = 0.27 but together with
the foil and air-gap on both sides and the rest of the roof it bumps up to
1.4-5.6. For 20mm is 0.02/0.0366 = 0.55, but Skillion Roof Green 20 total is
R2.2 out, R3.1 in.

https://www.foilboard.com.au/wp-content/uploads/2023/04/FOILBOARD-FINAL-2023-APRIL-DIGITAL.pdf

This has the raw R values not including radiant foil effects, and shows it as
R0.13 per 5mm thickness.

outdoor air        0.04
outside foil gap   0.71
foamboard 10mm     0.26
inside foil gap    0.71
indoor air         0.12

total = R1.84, of which only 0.26 is the board. But without the foilboard and
just a cavity you have 0.04+0.16+0.12 = 0.32, so foilboard adds R1.52, of which
R1.28 is just due to the double-sided foil&air-gaps.

### Corflute

Corflute is polypropyline cardboard. Polypropyline has K=0.22W/mK d=0.9g/cm^3.
Tunnelcore 5mm has d=0.18g/cm^2, which means the cross section is only
0.18/0.9=0.2 or 20% solid. This suggests a 0.35mm thickness wall.

Calculations in the following spreadsheet give the corflute R values of;

https://docs.google.com/spreadsheets/d/17m0OmeC3FWWI7BKIIBJTtw7Bf-GojhWo89HRaAEcK3U/edit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

tunnelcore 3mm R0.052
tunnelcore 5mm R0.075
tunnelcore 8mm R0.095

###Modeling

3x3x2m room,

floor=9m^2
roof=9m^2
walls=24m^2
total=42m^2

10degree diff, all R=2.0 = 5W/m^2 so 42*5=210W to maintain a 10deg temp
difference, or 420W for 20deg.

On hot days the floor is going to be a problem with heat rising through it.

layer               R
-------------
outside air       0.04
suntuf roof       0.17 (does this include the air-gap? Should this be 0.0035
for just the sheet?)
air gap (dn)      1.2?
foilboard 20mm    0.52
air gap (dn)      1.2?
ceiling sheet     0.003/0.14=0.02
indoor air        0.12
total 3.28

##Thermal bridging effects.

Wood is more heat conductive than air, so heat will conduct through timber
past air gaps. This can even cause condensation on inside walls over the
studs, discolouring paint.

Metal nails and screws are also very conductive, at least 500x as conducitive
as wood, 

Pine with K=0.12 has R=L/K = 0.01/0.12 = R0.083 per 10mm, or R0.58 across the
70mm wall stud thickness. Foilboard is R0.26 per 10mm, and air-gaps with foil
are R0.71 horizontally. So 10mm foilboard in a wall void is 0.71+0.26+0.71=R1.68 compared
to R0.58 for the stud. This means, assuming energy flow through both is the
same, 1.1 degrees difference per W/m^2 energy flow, so for an overall R=2.0
void with a temp difference of 10degrees (5W/m^2), the wall in front of a stud
will be 5.5 degrees colder than the wall in front of a void. In practice it
could is lower because the energy flow through the low-resistance stud
will be higher than through the void and it equalizes with the inside
air.

For a wall over a foilboard void upto the indoor surface and including the indoor
air barrier it is;

Rv=2.0
Uv=1/2.0=0.5
Rvw=Rv+Rai=2.0+0.12 = 2.12
Uvw=1/Rvw=1/2.12 = 0.472

For a wall over a stud upto the indoor surface;

Rs=0.9
Us=1/Rs=1/0.9 = 1.1
Rsw=Rs+Rai=0.9+0.12 = 1.02
Usw=1/Rsw=1/1.02 = 0.980

For dt=10deg between inside and outside, heat through void wall and stud wall;

dt=10deg
Evw=Uvw*dt=0.472*10=4.72W/m^2
Esw=Usw*dt=0.980*10=9.80W/m^2

So temp difference at the inside wall surface is;

dtv = Rv*Evw = 2.0*4.72=9.44deg
dts = Rs*Esw = 0.9*9.80=8.82deg
dtvs = dtv-dts=9.44-8.82=0.62deg
Esw/Evw=9.80/4.72 = 2.08x

So the wall over a stud will be 0.62 degrees colder than the wall over a
foilboard void per 10deg of difference between the inside and outside air, and
heat flow through the stud is more than 2x/m^2 of the flow through the void.

If studs make up 3.5cm/45cm~=8% of the wall, the overall wall is;

Utw=0.92*Uvw+0.08*Usw=0.92*0.472+0.08*0.980 = 0.513W/m^2.K
Rtw=1/U=1/0.51264 = 1.95m^2.K/W
Etw=Utw*dt=0.513*10 = 5.13W/m^2

Rvw-Rtw=2.12-1.95 = 0.17
Etw-Evw=5.13-4.72 = 0.41W/m^2
Etw/Evw=5.13/4.72 = 1.09x

So the studs lower the overall wall by R0.17, and increase the energy flow by
0.41W/m^2 or 9%.

Now lets put the foilboard over the outside studs, and add a 10mm wooden cavity
batten over the studs. The void wall has the same R/U values, but the stud becomes;

R's=Rs+Rf10+Lb/Kwood=0.9+0.26+0.01/0.12=1.24
U's=1/1.24=0.806

R'sw=R's+Rai=1.24+0.12=1.36
U'sw=1/1.36=0.735

E'sw=U'vw*dt=0.735*10=7.35W/m^2

dt's=R's*E'sw=1.24*7.35=9.11deg
dt'vs=dtv-dt's=9.44-9.11=0.33deg
E'sw/Evw=7.35/4.72 = 1.56x

U'tw=0.92*Uvw+0.8*U'sw=0.92*0.472+0.08*0.735=0.493
R'tw=1/0.493=2.03
E'tw=U'tw*dt=0.493*10 = 4.93W/m^2

Rvw-R'tw=2.12-2.03 = 0.09
E'tw-Evw=4.93-4.72 = 0.21W/m^2
E'tw/Evw=4.93/4.72 = 1.04x  

Comparing with/without thermal break;

R's-Rs=1.24-0.9 = 0.32
R'tw-Rtw=2.03-1.95 = 0.08
E'tw-Etw=4.93-5.13 = -0.20W/m^2
E'tw/Etw=4.93/5.13 = 0.94x
dt'vs-dtvs=0.33-0.62 = -0.29deg
dt'vs/dtvs=0.33/0.62 = 0.53x

So the foilboard thermal break improves wall by R0.08 and reduces the wall
temp difference over studs by 0.29deg per 10deg of temp difference, or nearly
halves the temp difference. It also reduces the energy flow by 0.2W/m^s, or 6%.

Using an insulating cavity batten increases the stud by a further R0.17, which
should add about half as much again.

### Thermal bridging through fastners.

The effect of metal nails/screws might not be trivial. For 10G screws are
4.8mm diameter and 50~65mm long. That's an area of about 18mm^2, and with 4
per 2m stud they make up (4*18)/(35*2000) = 0.1% of the stud area and go 71%
of the depth. However, with K values of 50.2/0.12 = 418x pine they do this to
the stud U value;

Lr=Ls-Lf

Rfr=Rf+Rr=Lf/Ksteel+Lr/Kwood = (Lf*Kwood + Lr*Ksteel)/(Ksteel*Kwood)
Ufr=1/Rfr=(Ksteel*Kwood)/(Lf*Kwood + Lr*Ksteel)
   = (50.2*0.12)/(0.05*0.12+0.02*50.2) = 5.96
Us=Ls/Kwood = 0.07/0.12 = 0.58
Rs=1/Us=1/0.58=1.72
Ufs=0.001*Ufr + 0.999*Us
   = 0.001*5.96 + 0.999*0.58 = 0.585
Rfs=1/Ufs= 1/0.585 = 1.71

Rfs-Rs=1.71-1.72 = -0.01
Rfs/Rs=1.71/1.72 = 0.994

So the screws lower the stud by R0.01 or 0.6%, a trivial amount. The Lr gap in
the stud without faster significantly saves this, acting as a thermal break.
If the faster goes all the way through, we get;

Ufr=Ksteel/Lf=717.1
Ufs=0.001*Ufr + 0.999*Us = 0.001*717.1 + 0.999*0.58 = 1.30
RfS=1/Ufs=0.769

Rfs-Rs=0.769-1.72 = -0.95
Rfs/Rs=0.769/1.72 = 0.45

So 2xG10/m screws all the way through a 35x70mm stud drops the stud by R0.95
or 55%!

This thermal bridging effect also affects fastners through foilboard, and
probably even more!

I've seen online talk of using plastic nails to avoid this problem. I'm not
sure if they were joking, does such a thing exist?

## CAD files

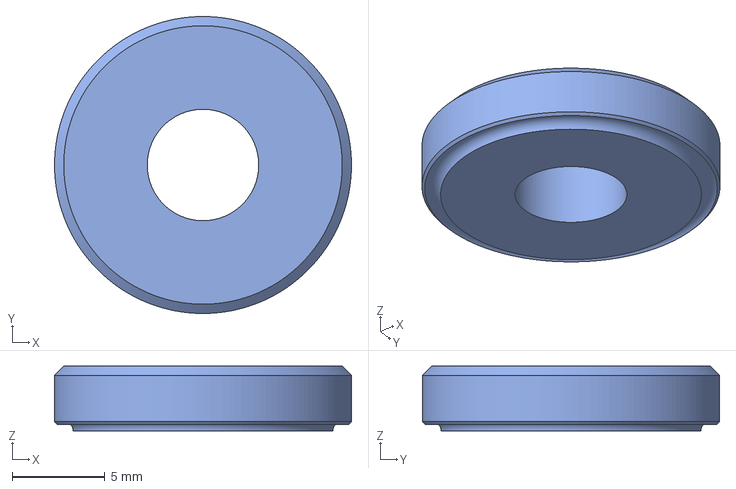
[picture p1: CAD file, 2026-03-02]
models/FastnerHole6.3mf
16.0 x 16.0 x 3.50 mm

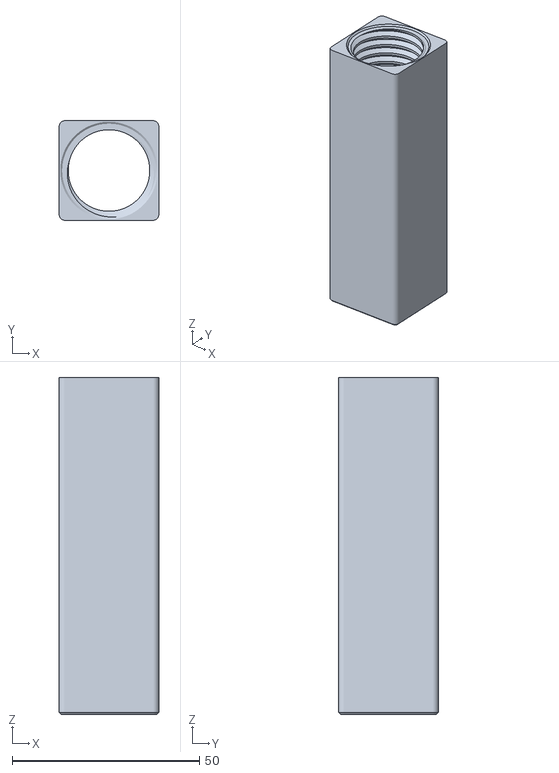
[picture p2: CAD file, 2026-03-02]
models/Insert_30x30_M24_x90_v1.2.0.stl
26.6 x 26.6 x 90.0

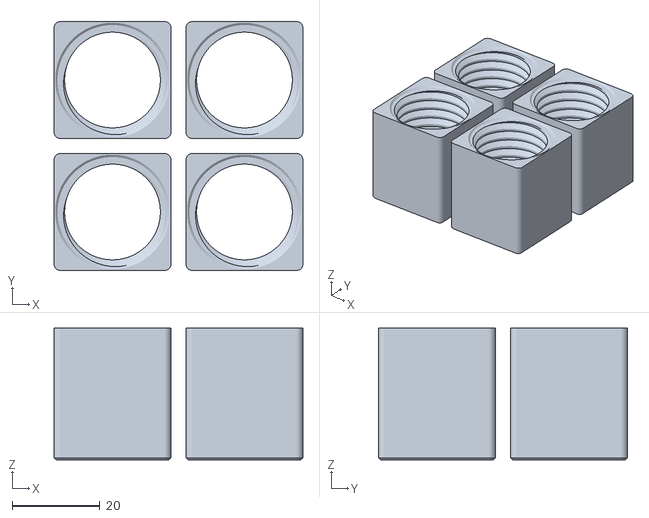
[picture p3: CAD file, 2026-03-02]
models/Insert_30x30_M24_x30_V1.2.1_x4.stl
56.6 x 56.6 x 30.0

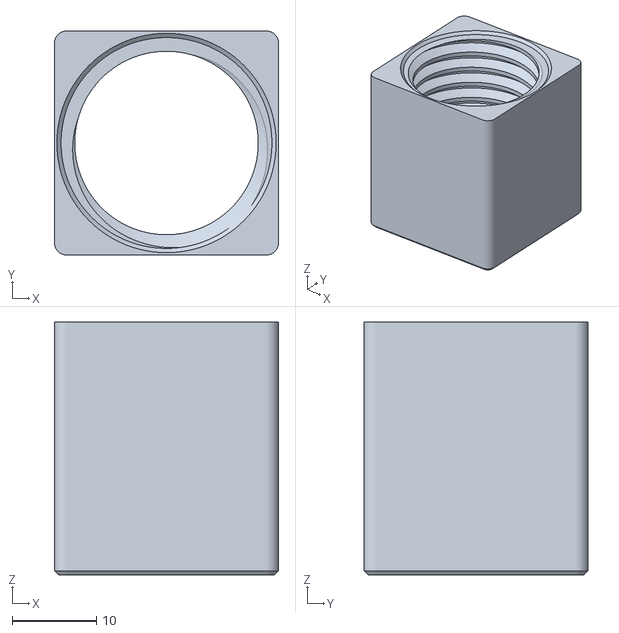
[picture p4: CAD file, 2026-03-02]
models/Insert_30x30_M24_x30_v1.0.2.stl
26.6 x 26.6 x 30.0

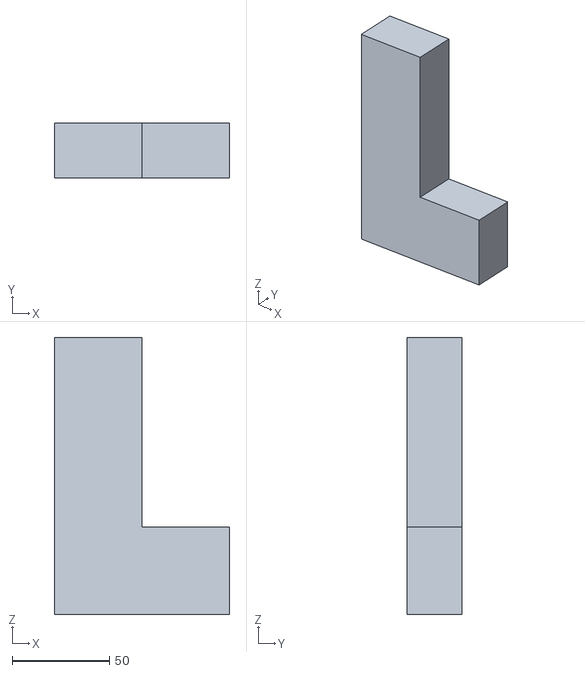
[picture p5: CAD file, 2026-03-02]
models/Pockethole Jig - Offset Insert.stl
90.0 x 28.0 x 142.2

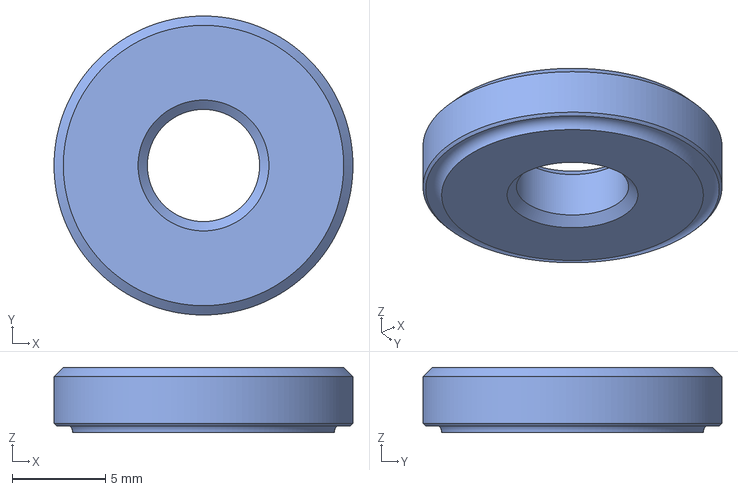
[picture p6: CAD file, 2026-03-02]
models/Ring_v1.0.1.3mf
16.0 x 16.0 x 3.50 mm

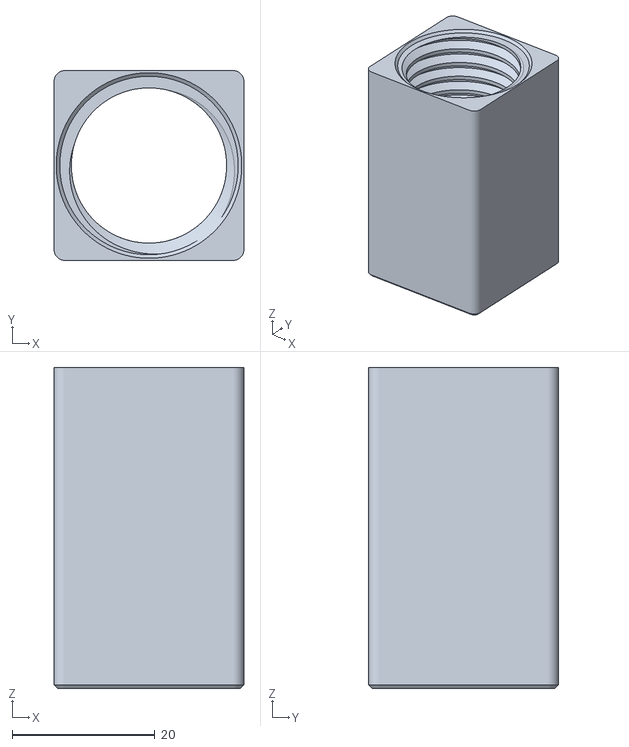
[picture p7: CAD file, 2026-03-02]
models/Insert_30x30_M24_x45_v1.1.0.stl
26.6 x 26.6 x 45.0

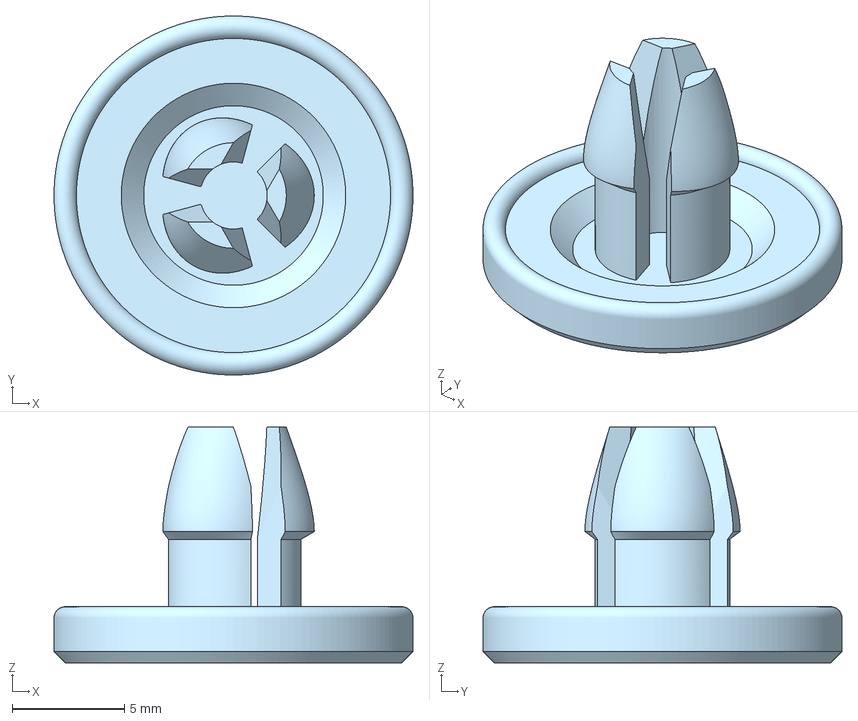
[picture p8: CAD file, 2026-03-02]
models/Clip_v1.0.0.3mf
16.0 x 16.0 x 10.5 mm

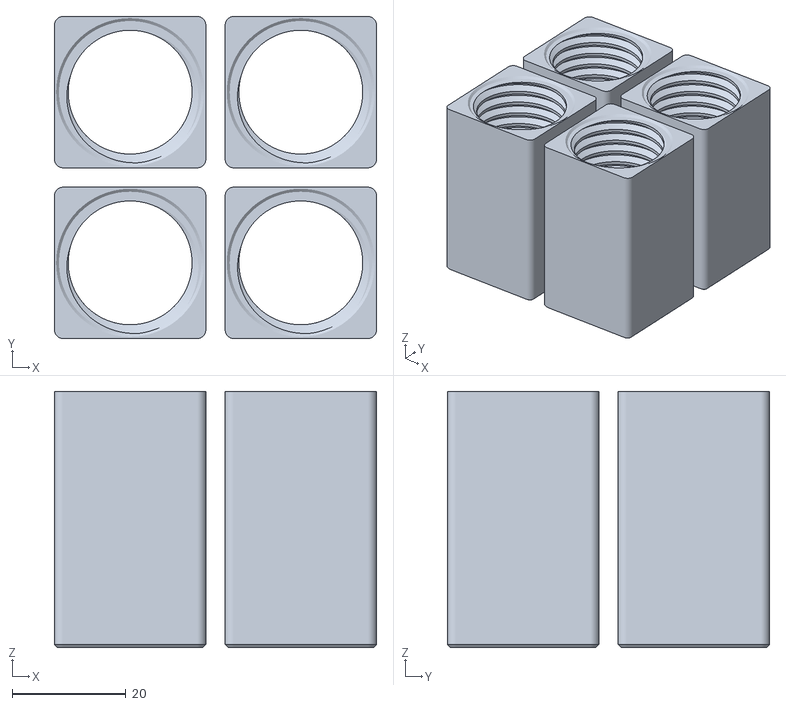
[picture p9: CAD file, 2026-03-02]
models/Insert_30x30_M24_x45_v1.1.0x4.stl
56.6 x 56.6 x 45.0

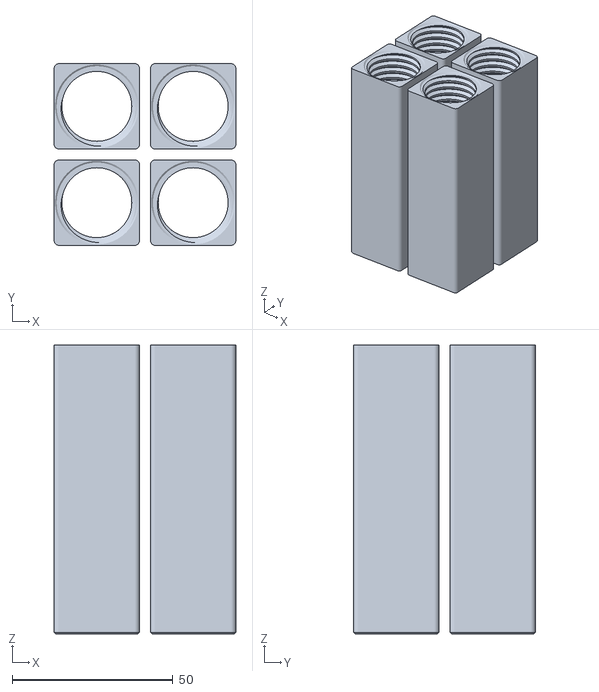
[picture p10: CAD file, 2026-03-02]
models/Insert_30x30_M24_x90_v1.2.0x4.stl
56.6 x 56.6 x 90.0

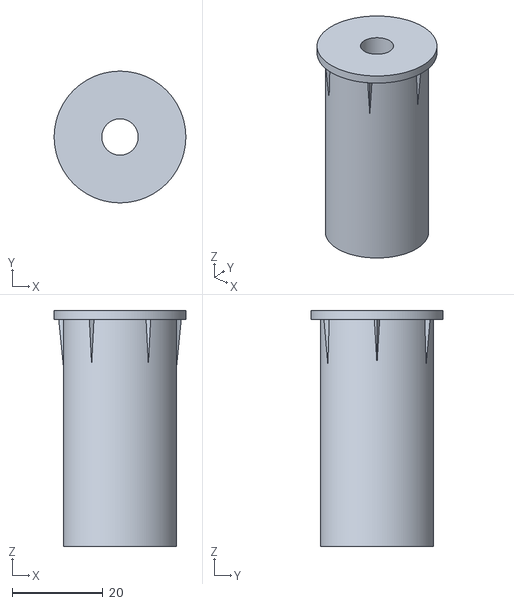
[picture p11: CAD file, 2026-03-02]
models/Jig Washer Hole Insert.stl
29.0 x 29.0 x 52.0

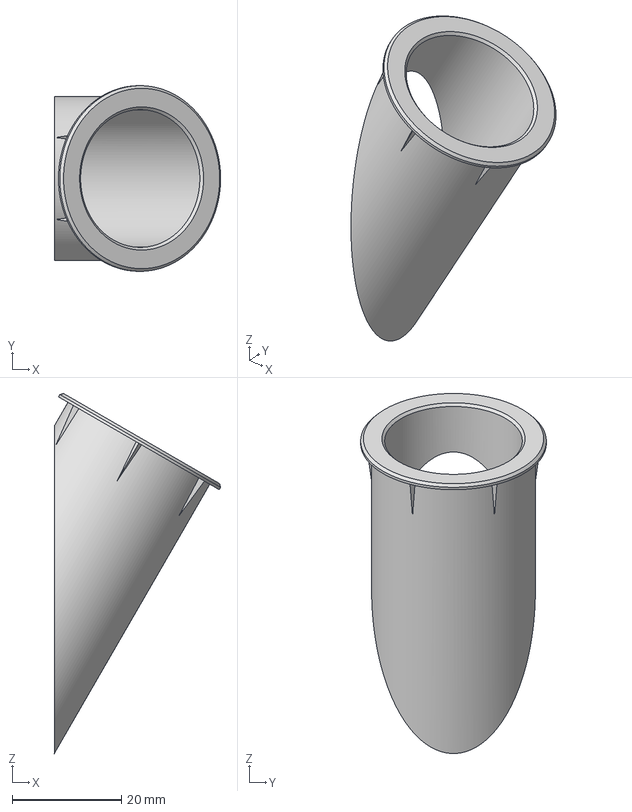
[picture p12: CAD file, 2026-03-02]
models/Pockethole Jig - Washer Hole Lining.3mf
30.4 x 34.0 x 65.9 mm

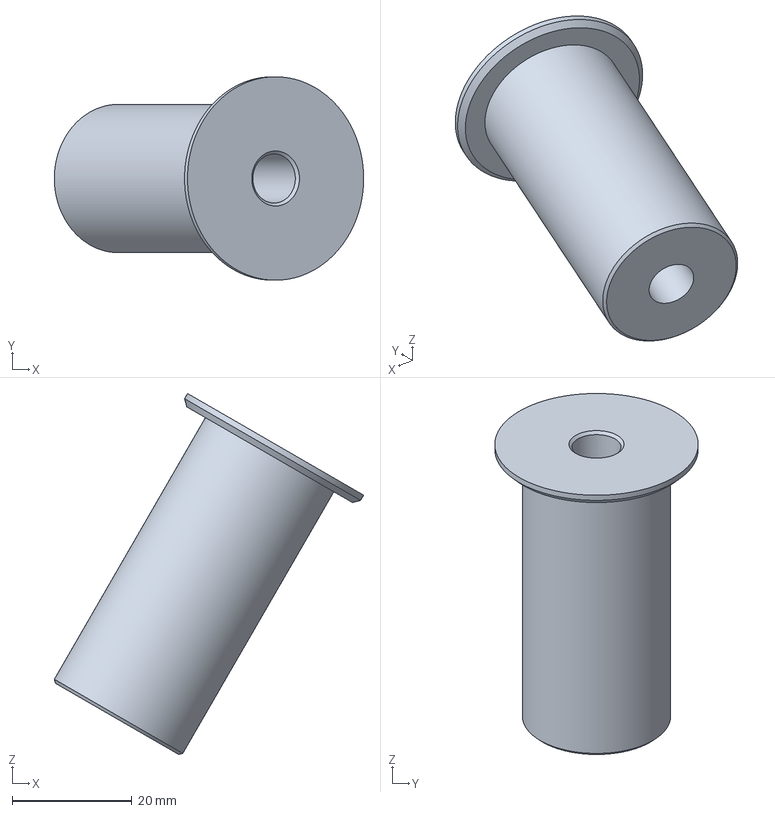
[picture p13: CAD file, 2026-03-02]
models/Pockethole Jig - Screw Hole Insert.3mf
51.7 x 34.0 x 60.3 mm

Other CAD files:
models/FastnerHole2.3mf
models/FastnerHole1.3mf
models/30x30 M24 insert.stl
models/Insert_30x30_M24_x30_v1.0.1.stl
